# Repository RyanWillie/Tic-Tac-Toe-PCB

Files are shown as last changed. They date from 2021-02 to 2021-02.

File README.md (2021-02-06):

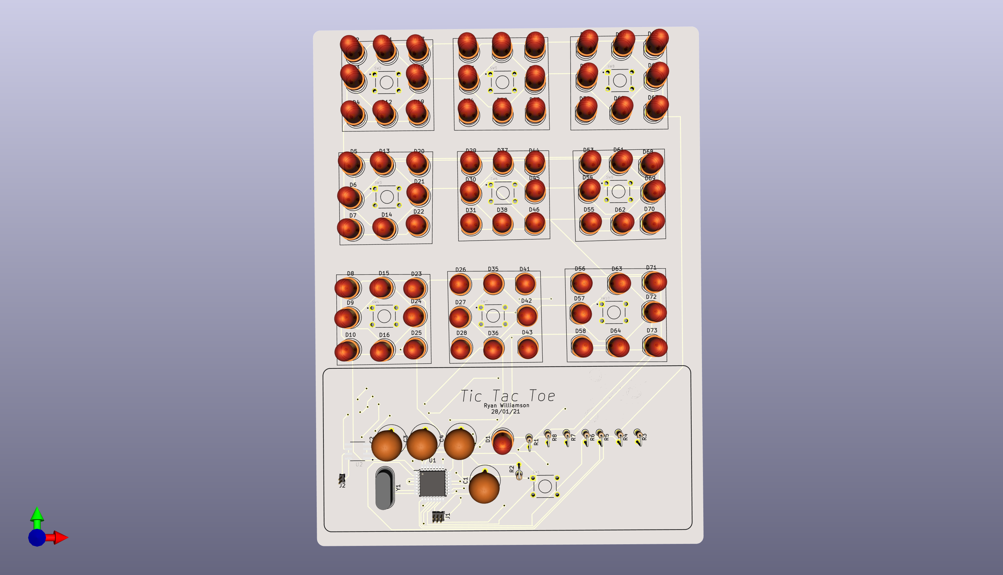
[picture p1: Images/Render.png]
KiCad Render


# Tic-Tac-Toe-PCB

A continuation of my Hobby PCB designs is the arduino based Tic Tac Toe circuit, utilising some surface mount components this circuit was aimed to give some practical experience in implementing a microcontroller from scratch utilising the reference design sheets. Using multiplexing each grid is able to light up with an X or a O to indicate who has claimed the tile.

## Component Selection

The main principle of the component selection was to use readily available components with libraries available for easy and quick setup,as well as preferring breakout boards so that the components can be easily salvaged/replaced for other projects when it is not needed. Therefore the microcontroller will be an Arduino nano, and the popular NRF24L01 transciever as the available libary makes connection extremely easy.

## BOM
  - Arduino Nano
  - 72x LED
  - 9 x Switches
  - Crystal
  - Capacitors
  
## Proof of Concept
 No proof of concept was able to be created for this circuit due to the required components that were not on hand.

## PCB Design and Manufacturing
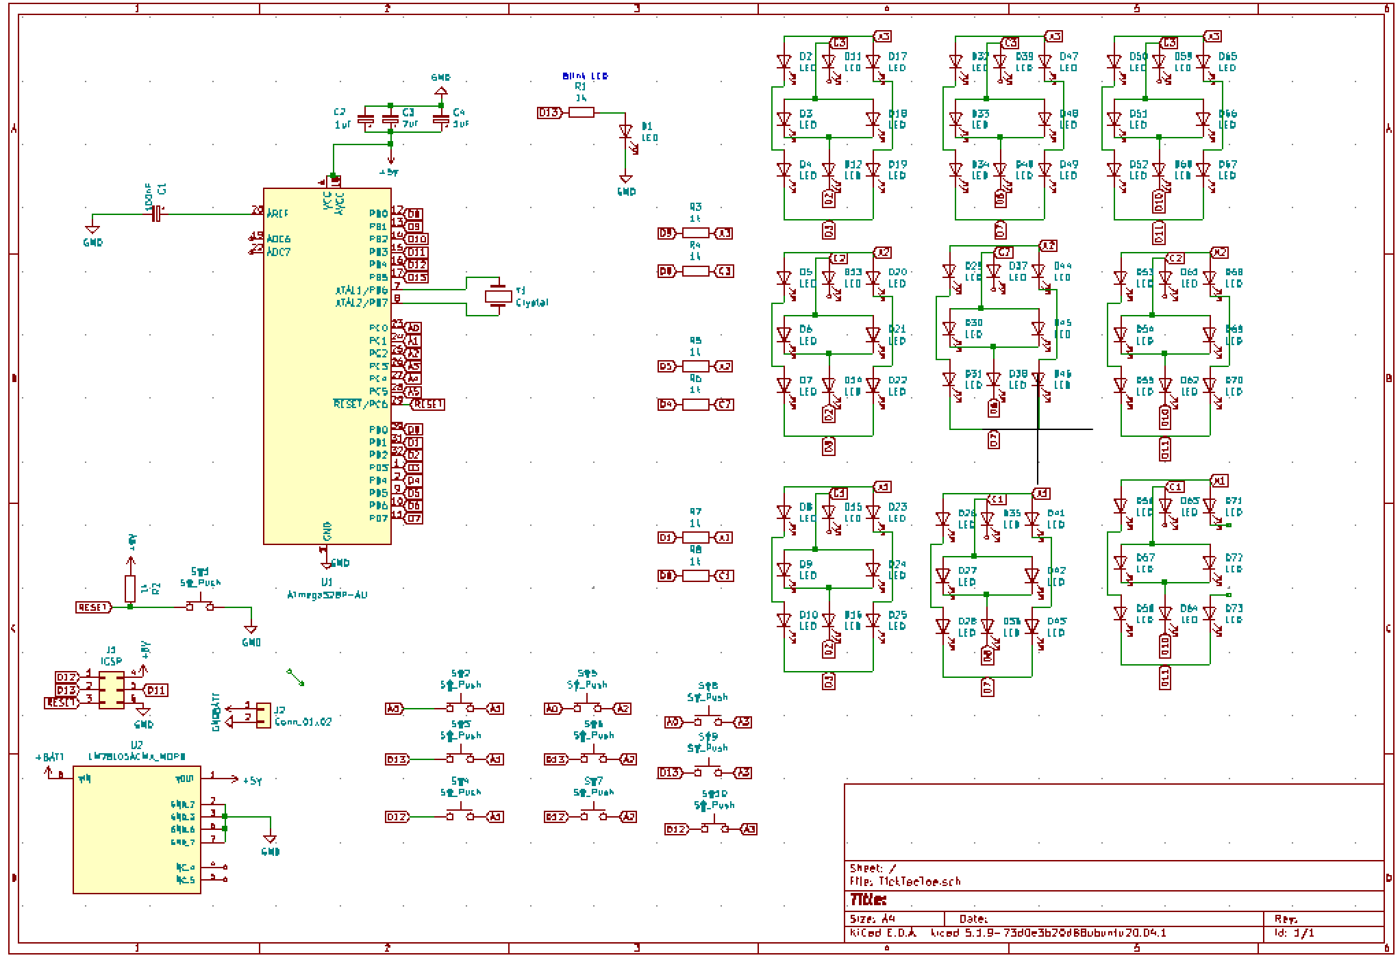
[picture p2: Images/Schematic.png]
KiCad Schematic

The open source program KiCad was used as the design software for the PCB, it is a 2 layer board designed to meet JLCPCB's requirements. As the board is a one off the space and shape requirements are purely to achieve the smallest practical footprint.

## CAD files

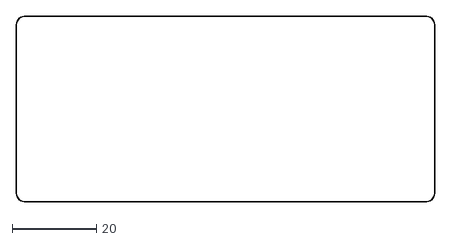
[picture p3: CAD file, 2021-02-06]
KiCad/CircuitOutline.dxf
99.0 x 44.0

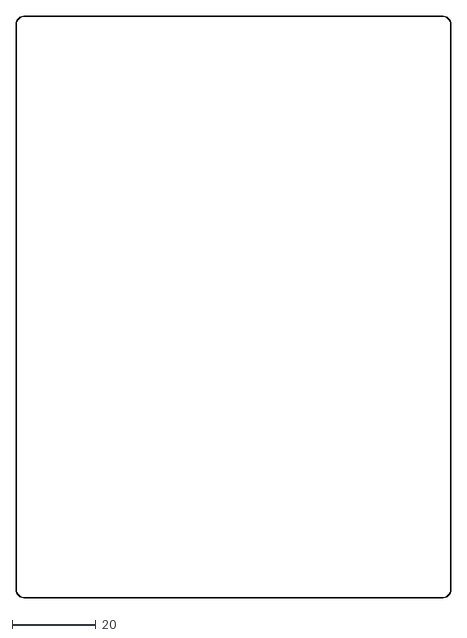
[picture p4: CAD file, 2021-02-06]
KiCad/PCBOutline.dxf
104.0 x 139.0

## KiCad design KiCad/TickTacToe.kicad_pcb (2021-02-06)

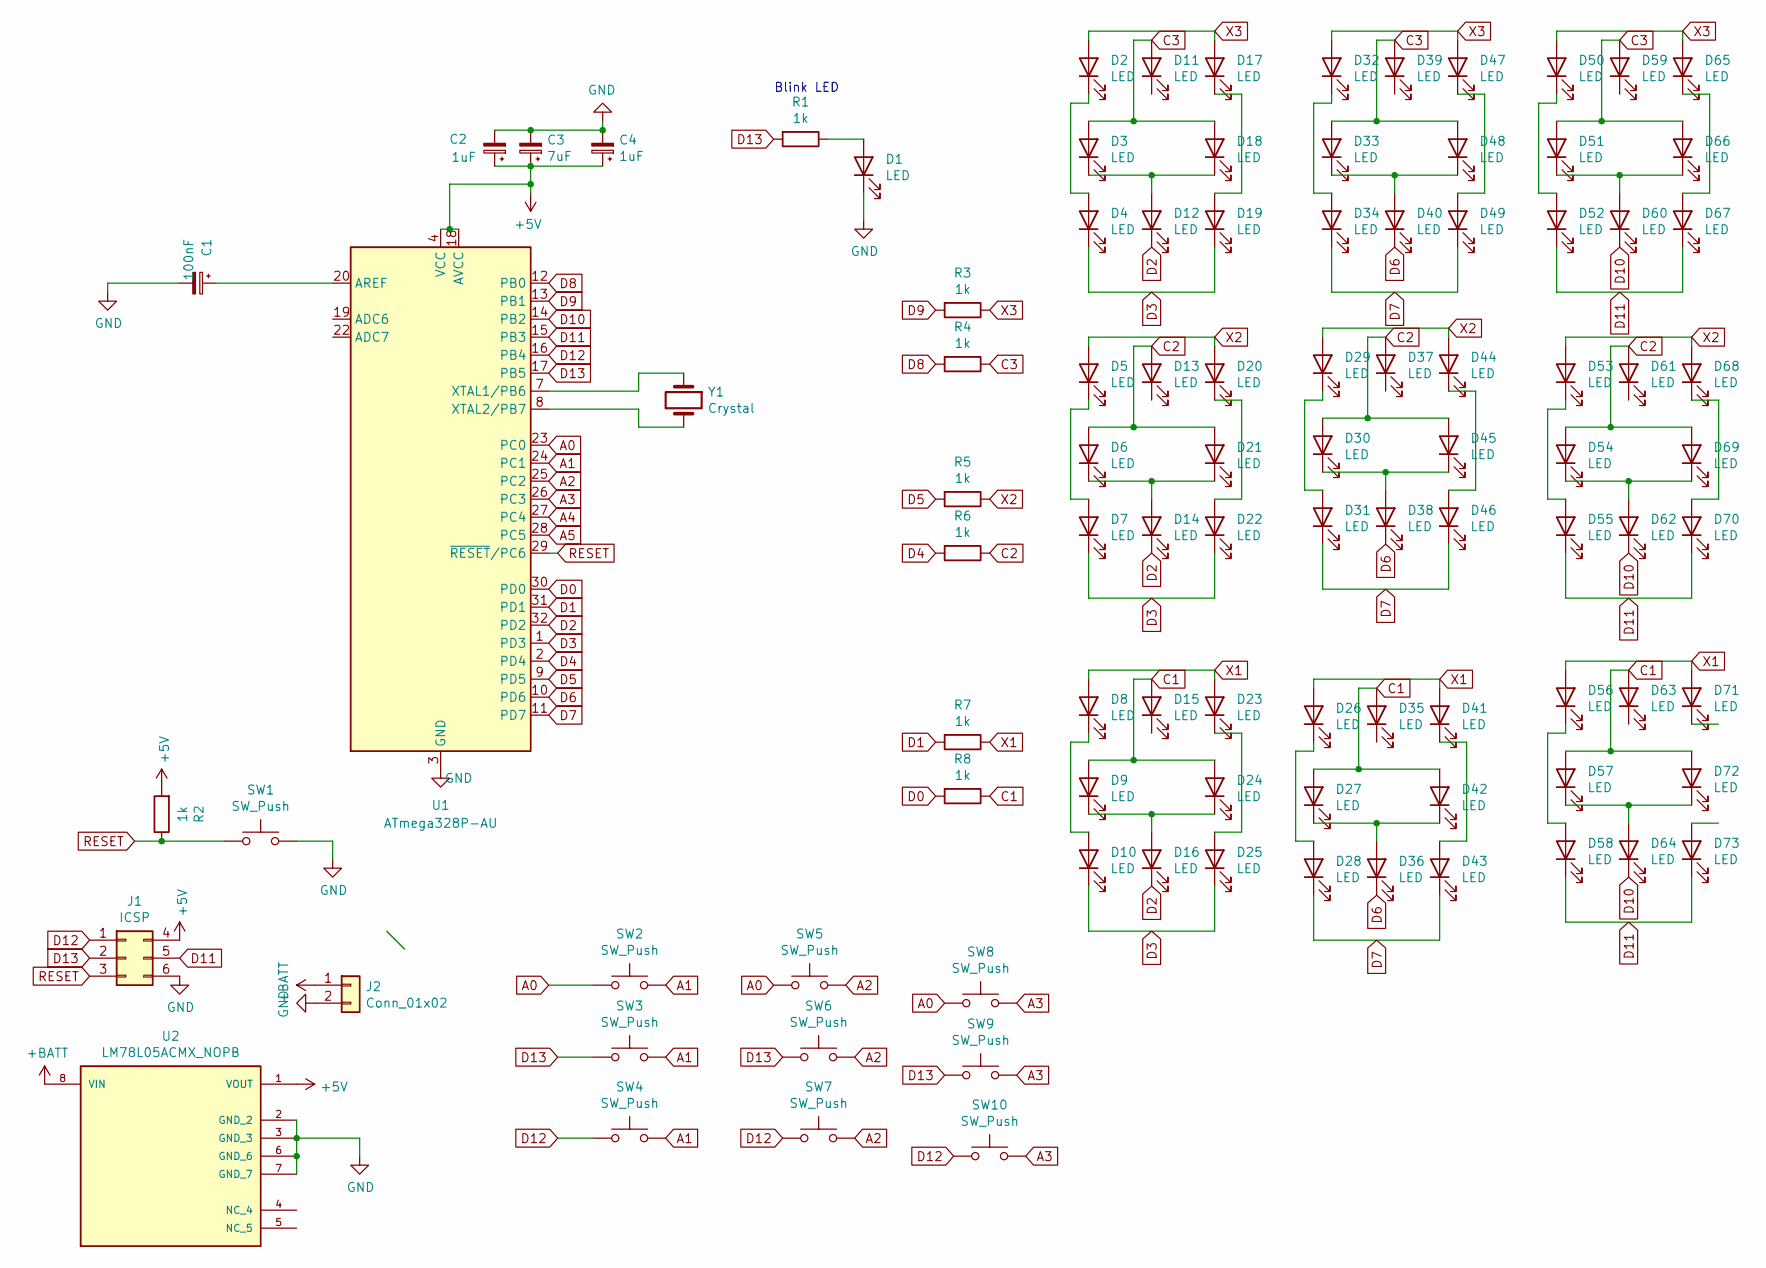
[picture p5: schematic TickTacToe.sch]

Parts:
C1: 100nF; CP_Radial_Tantal_D8.0mm_P5.00mm
C2, C4: 1uF; CP_Radial_Tantal_D8.0mm_P5.00mm
C3: 7uF; CP_Radial_Tantal_D8.0mm_P5.00mm
D1, D2, D3, D4, D5, D6, D7, D8, D9, D10, D11, D12, D13, D14, D15, D16, D17, D18, D19, D20, D21, D22, D23, D24, D25, D26, D27, D28, D29, D30, D31, D32, D33, D34, D35, D36, D37, D38, D39, D40, D41, D42, D43, D44, D45, D46, D47, D48, D49, D50, D51, D52, D53, D54, D55, D56, D57, D58, D59, D60, D61, D62, D63, D64, D65, D66, D67, D68, D69, D70, D71, D72, D73: LED; LED_D5.0mm
J1: ICSP; PinHeader_2x03_P1.00mm_Vertical
J2: Conn_01x02; PinHeader_1x02_P1.00mm_Vertical
R1, R2, R3, R4, R5, R6, R7, R8: 1k; R_Axial_DIN0204_L3.6mm_D1.6mm_P2.54mm_Vertical
SW1, SW2, SW3, SW4, SW5, SW6, SW7, SW8, SW9, SW10: SW_Push; SW_1825910-6-4
U1: ATmega328P-AU; TQFP-32_7x7mm_P0.8mm
U2: LM78L05ACMX_NOPB; SOIC127P599X175-8N; PARTREV L
Y1: Crystal; Crystal_HC49-4H_Vertical

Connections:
+5V: C2.1, C3.1, C4.1, J1.4, R2.2, U1.4 (VCC), U1.6 (VCC), U1.18 (AVCC), U2.1 (VOUT)
+BATT: J2.1, U2.8 (VIN)
A0: SW2.1, SW5.1, SW8.1, U1.23 (PC0)
A1: SW2.2, SW3.2, SW4.2, U1.24 (PC1)
A2: SW5.2, SW6.2, SW7.2, U1.25 (PC2)
A3: SW8.2, SW9.2, SW10.2, U1.26 (PC3)
A4: U1.27 (PC4)
A5: U1.28 (PC5)
C1: D9.2 (A), D15.2 (A), D24.2 (A), D27.2 (A), D35.2 (A), D42.2 (A), D57.2 (A), D63.2 (A), D72.2 (A), R8.1
C2: D6.2 (A), D13.2 (A), D21.2 (A), D30.2 (A), D37.2 (A), D45.2 (A), D54.2 (A), D61.2 (A), D69.2 (A), R6.1
C3: D3.2 (A), D11.2 (A), D18.2 (A), D33.2 (A), D39.2 (A), D48.2 (A), D51.2 (A), D59.2 (A), D66.2 (A), R4.1
D0: R8.2, U1.30 (PD0)
D1: R7.2, U1.31 (PD1)
D2: D12.1 (K), D14.1 (K), D16.1 (K), U1.32 (PD2)
D3: D4.1 (K), D7.1 (K), D10.1 (K), D19.1 (K), D22.1 (K), D25.1 (K), U1.1 (PD3)
D4: R6.2, U1.2 (PD4)
D5: R5.2, U1.9 (PD5)
D6: D36.1 (K), D38.1 (K), D40.1 (K), U1.10 (PD6)
D7: D28.1 (K), D31.1 (K), D34.1 (K), D43.1 (K), D46.1 (K), D49.1 (K), U1.11 (PD7)
D8: R4.2, U1.12 (PB0)
D9: R3.2, U1.13 (PB1)
D10: D60.1 (K), D62.1 (K), D64.1 (K), U1.14 (PB2)
D11: D52.1 (K), D55.1 (K), D58.1 (K), D67.1 (K), D70.1 (K), D73.1 (K), J1.5, U1.15 (PB3)
D12: J1.1, SW4.1, SW7.1, SW10.1, U1.16 (PB4)
D13: J1.2, R1.2, SW3.1, SW6.1, SW9.1, U1.17 (PB5)
GND: C1.2, C2.2, C3.2, C4.2, D1.1 (K), J1.6, J2.2, SW1.2, U1.3 (GND), U1.5 (GND), U1.21 (GND), U2.2 (GND_2), U2.3 (GND_3), U2.6 (GND_6), U2.7 (GND_7)
unnamed: C1.1, U1.20 (AREF)
unnamed: D1.2 (A), R1.1
unnamed: D2.1 (K), D4.2 (A)
unnamed: D5.1 (K), D7.2 (A)
unnamed: D8.1 (K), D10.2 (A)
unnamed: D3.1 (K), D12.2 (A), D18.1 (K)
unnamed: D6.1 (K), D14.2 (A), D21.1 (K)
unnamed: D9.1 (K), D16.2 (A), D24.1 (K)
unnamed: D17.1 (K), D19.2 (A)
unnamed: D20.1 (K), D22.2 (A)
unnamed: D23.1 (K), D25.2 (A)
unnamed: D26.1 (K), D28.2 (A)
unnamed: D27.1 (K), D36.2 (A), D42.1 (K)
unnamed: D29.1 (K), D31.2 (A)
unnamed: D30.1 (K), D38.2 (A), D45.1 (K)
unnamed: D32.1 (K), D34.2 (A)
unnamed: D33.1 (K), D40.2 (A), D48.1 (K)
unnamed: D41.1 (K), D43.2 (A)
unnamed: D44.1 (K), D46.2 (A)
unnamed: D47.1 (K), D49.2 (A)
unnamed: D50.1 (K), D52.2 (A)
unnamed: D51.1 (K), D60.2 (A), D66.1 (K)
unnamed: D53.1 (K), D55.2 (A)
unnamed: D54.1 (K), D62.2 (A), D69.1 (K)
unnamed: D56.1 (K), D58.2 (A)
unnamed: D57.1 (K), D64.2 (A), D72.1 (K)
unnamed: D65.1 (K), D67.2 (A)
unnamed: D68.1 (K), D70.2 (A)
unnamed: U1.7 (XTAL1/PB6), Y1.1
unnamed: U1.8 (XTAL2/PB7), Y1.2
RESET: J1.3, R2.1, SW1.1, U1.29 (~RESET~/PC6)
X1: D8.2 (A), D23.2 (A), D26.2 (A), D41.2 (A), D56.2 (A), D71.2 (A), R7.1
X2: D5.2 (A), D20.2 (A), D29.2 (A), D44.2 (A), D53.2 (A), D68.2 (A), R5.1
X3: D2.2 (A), D17.2 (A), D32.2 (A), D47.2 (A), D50.2 (A), D65.2 (A), R3.1

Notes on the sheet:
Blink LED

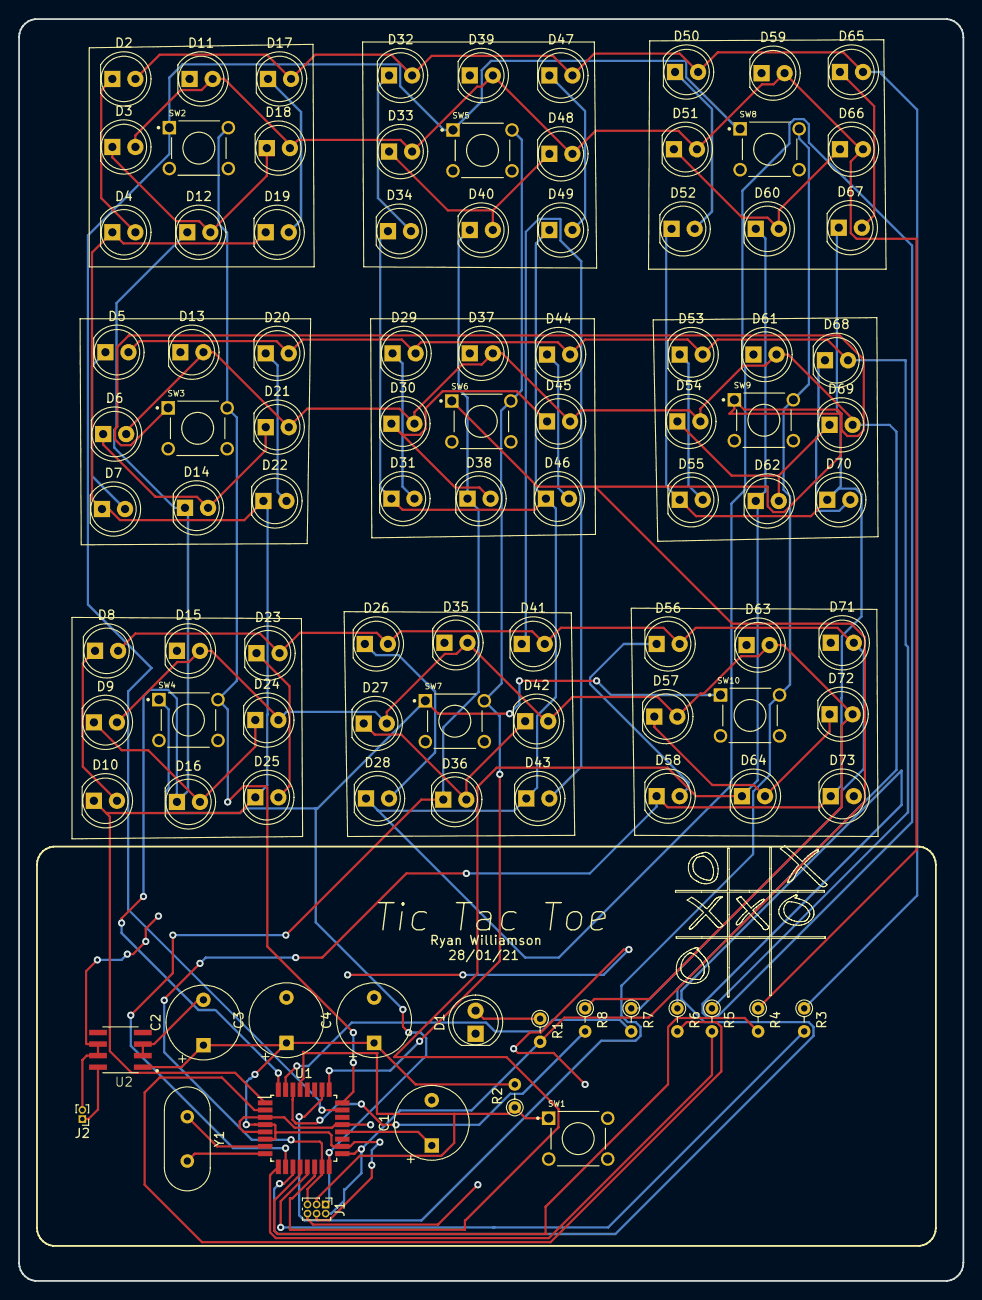
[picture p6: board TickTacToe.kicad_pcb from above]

Board: 2 copper layers, 104.0 x 139.0 mm, 100 parts (0 on the bottom side), 58 nets.
